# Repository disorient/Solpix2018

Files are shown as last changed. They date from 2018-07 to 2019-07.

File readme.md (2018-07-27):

# SolPix solar light flasher

This is a small mod board for converting a normal, non flashing [solar light](http://pdf.lowes.com/installationguides/840623104422_install.pdf)

## Installation Steps
briefly:

1. disassemble top of case, removing clear plastic top, 4 screws, black plastic lid, rubber gasket.
2. cut D2 diode leaving as much of the wire on it's leads attached to the board.
3. solder in the mod board along its long edge, with components facing up.
4. solder a wire from the remaining pad on the mod board to a gnd connection on the original board.
5. turn on to test.
6. reassemble top of case.

## Building the firmware
The flasher uses a [WCH CH554 microcontroller](www.wch.cn/products/CH554.html) and is programmed using the [CH554 SDCC](https://github.com/Blinkinlabs/ch554_sdcc) toolchain. It should work under macOS, Linux, and Windows (but was developed under a Windows environment). Once the toolchain is set up, the firmware can be built by running 'make' in the firware directory. Pre-compiled firmware releases are also available in the releases/ directory.

A nice feature of the WCH parts is that they have a hardware USB peripheral with a built-in bootloader, so they can be programmed without needing an extra tool. Pads for the USB connections are available on one edge of the PCB.

## PCB design
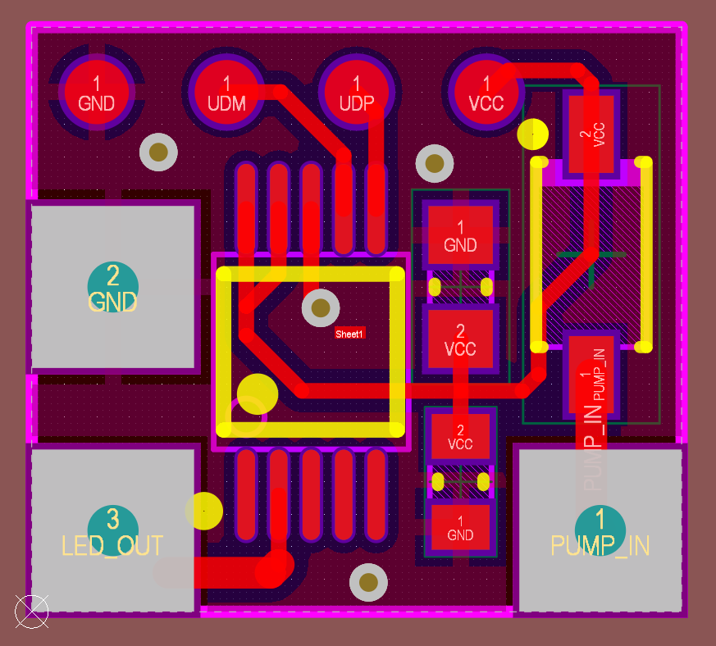
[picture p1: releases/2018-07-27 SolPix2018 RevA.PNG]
PCB image


The PCB was designed in Altium. The schematics and gerber for the release are available in the releases/ subdirectoy.

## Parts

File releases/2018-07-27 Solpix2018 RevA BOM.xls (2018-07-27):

PartType | Designator | Comment | Description | ComponentLink2URL | Pins | LibRef | Manufacturer | Quantity | Model:Footprint
CAP 2.2uF 6.3V 0603(1608) | C1 | CAP 2.2uF 6.3V 0603(1608) | CAP 2.2uF 6.3V ±10% 0603 (1608 Metric) Thickness 1mm SMD |  | 2.0 | CMP-1035-02754-1 |  | 1.0 | Chip Capacitor, Body 1.6x0.8mm, Height 1.0mm, IPC High Density
1N5819HW-7-F | D1 | 1N5819HW-7-F | 1.0 A Surface Mount Schottky Barrier Rectifier, 40 V, -65 to 125 degC, 2-Pin SOD-123 Package, RoHS, Tape and Reel | http://www.diodes.com/datasheets/ds30217.pdf | 2.0 | CMP-0303-00003-1 | Diodes Inc | 1.0 | SOD-123, 2-Leads, Body 2.85x1.7mm (max), Pitch 3.7mm
10K 5% 0603(1608) | R1 | 10K 5% 0603(1608) | 10K 0.1W 5% 0603 (1608 Metric) SMD |  | 2.0 | CMP-1012-00098-1 |  | 1.0 | Chip Resistor, Body 1.6x0.8mm, IPC Medium Density
CH554E | U1 | CH554E | 8-bit enhanced USB microcontroller |  | 10.0 | CH554E | WCH | 1.0 | Footprint from SZLCSC example

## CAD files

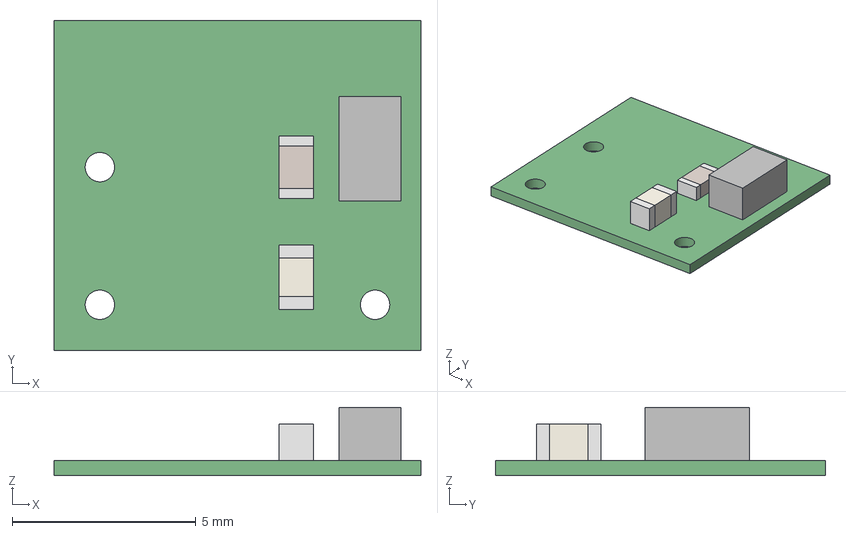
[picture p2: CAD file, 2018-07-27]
releases/2018-07-27 Solpix2018 RevA.step
10.0 x 9.00 x 1.86 mm
Board
Extruded x 7

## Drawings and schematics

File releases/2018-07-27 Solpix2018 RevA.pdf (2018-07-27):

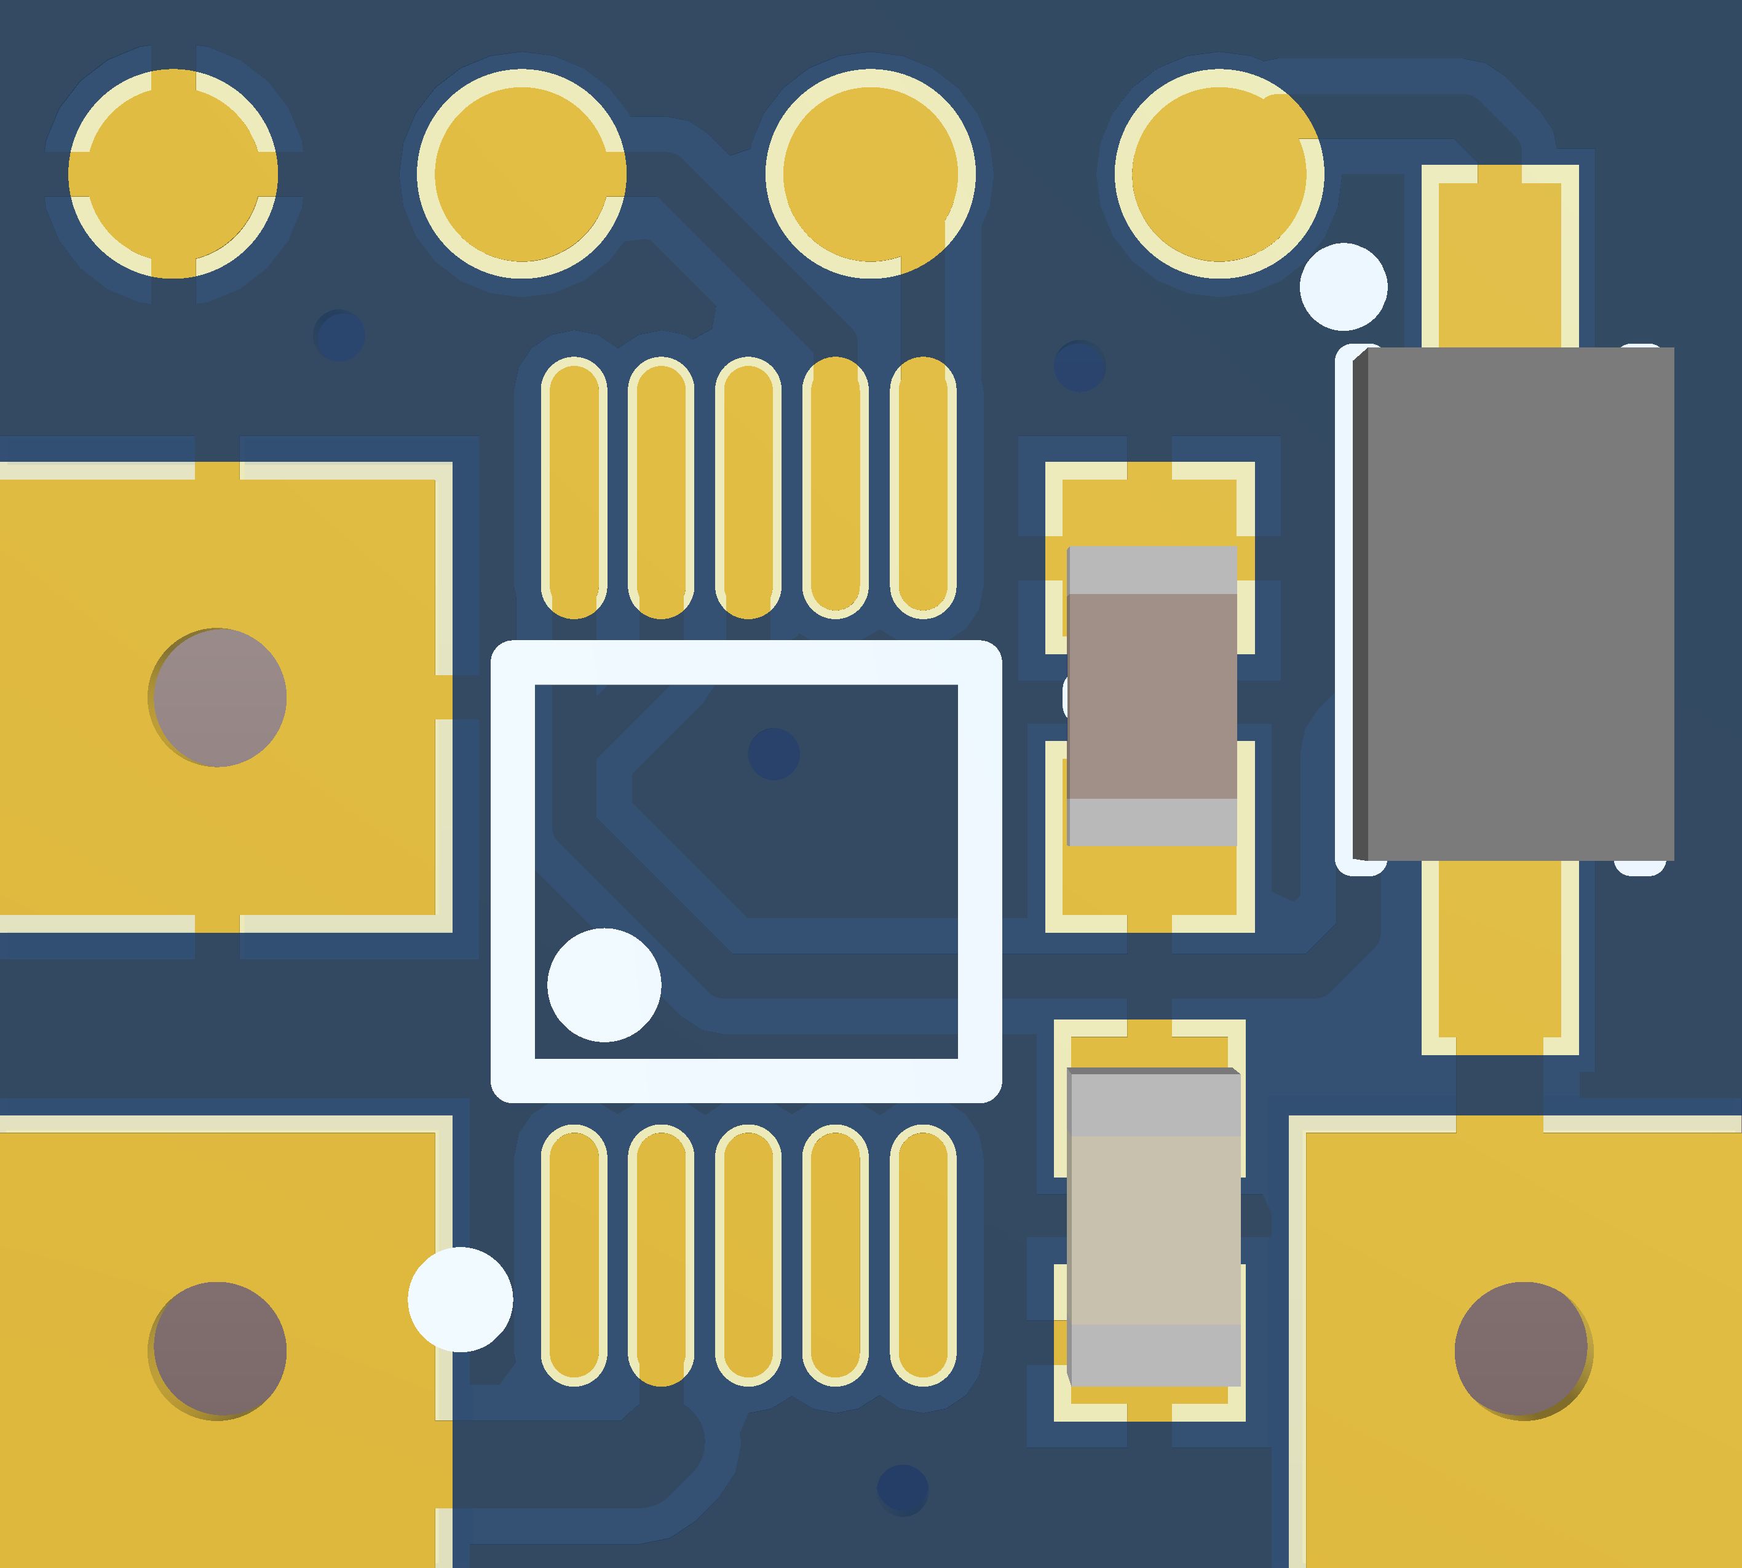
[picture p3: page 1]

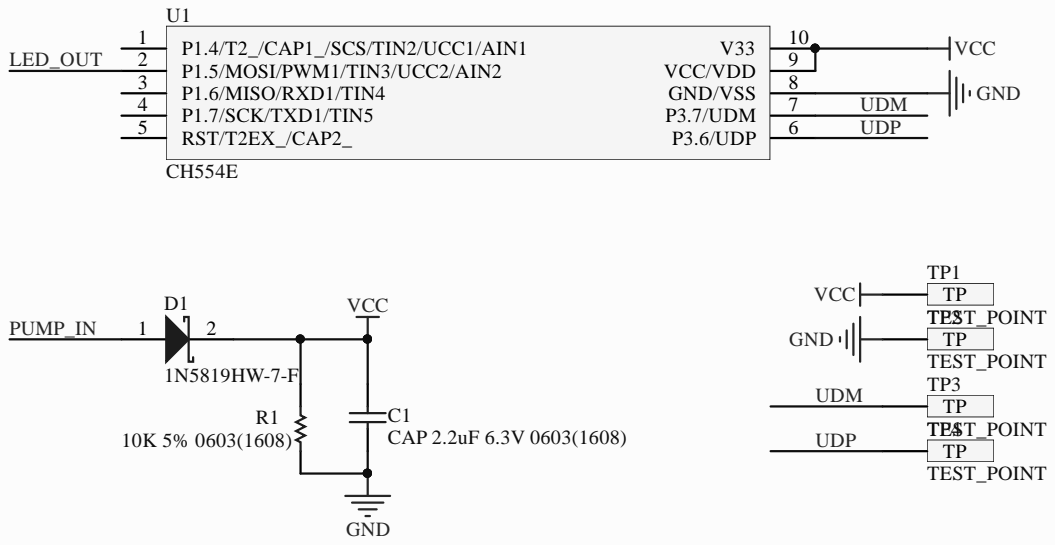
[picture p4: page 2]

* Title:

Project: PCB_Project1.PrjPCB | Revision: *

Date: 7/27/2018 Time: 5:05:16 PM | Sheet * of *

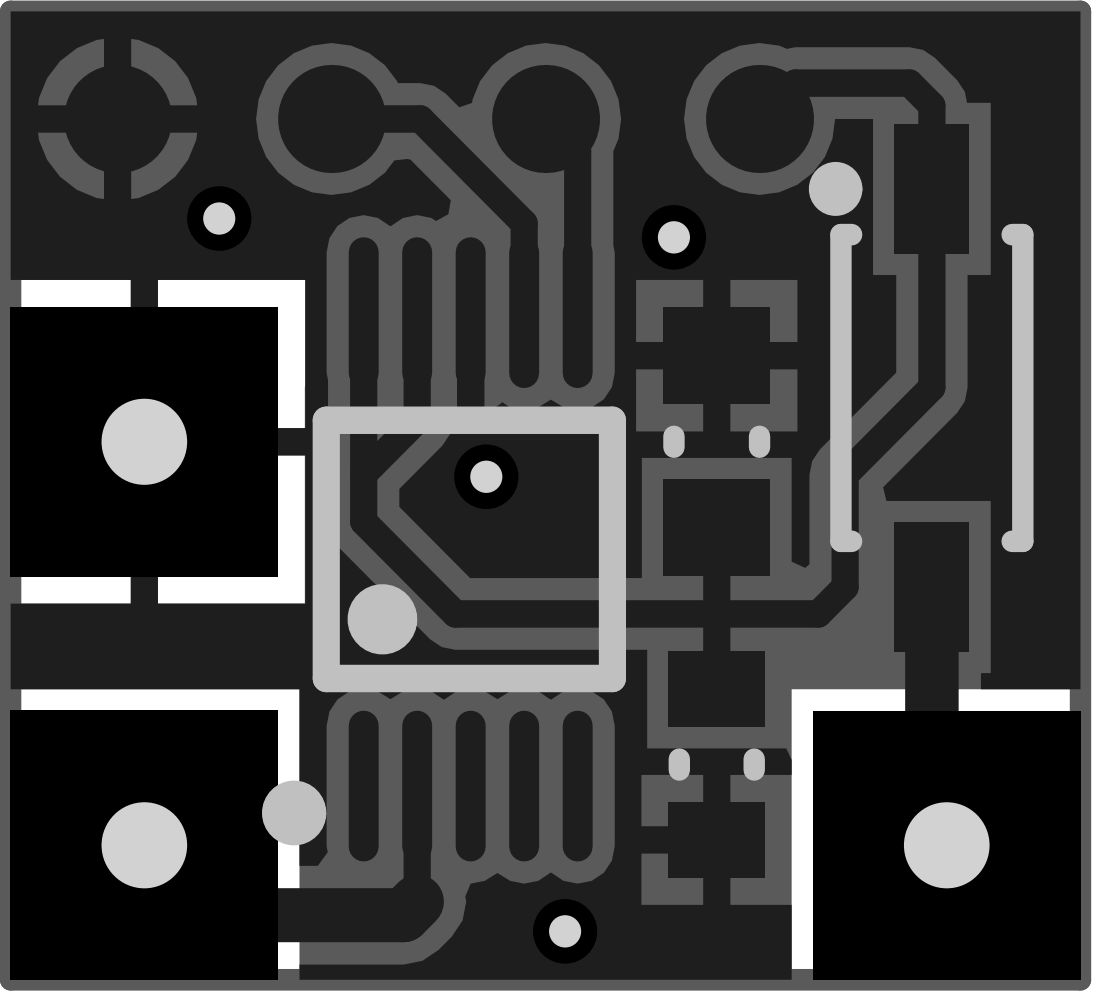
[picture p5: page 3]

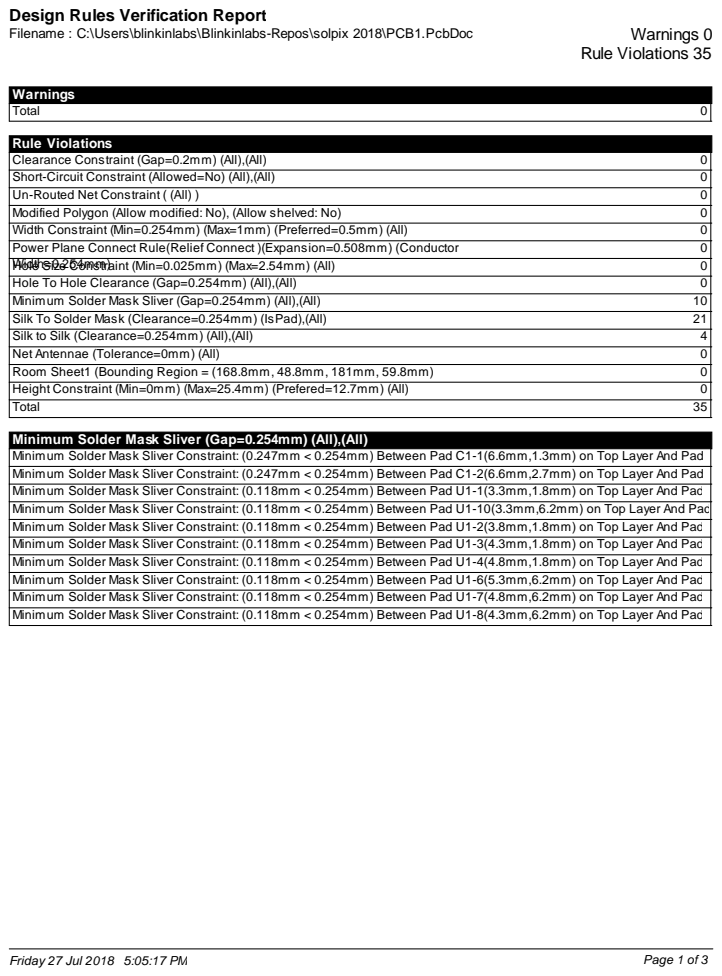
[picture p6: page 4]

Design Rules Verification Report

Rule Violations
Power Plane Connect Rule(Relief Connect )(Expansion=0.508mm) (Conductor
Width=0.254mm)

Minimum Solder Mask Sliver (Gap=0.254mm) (All),(All)
Minimum Solder Mask Sliver Constraint: (0.247mm < 0.254mm) Between Pad C1-1(6.6mm,1.3mm) on Top Layer And Pad
Minimum Solder Mask Sliver Constraint: (0.247mm < 0.254mm) Between Pad C1-2(6.6mm,2.7mm) on Top Layer And Pad
Minimum Solder Mask Sliver Constraint: (0.118mm < 0.254mm) Between Pad U1-1(3.3mm,1.8mm) on Top Layer And Pad
Minimum Solder Mask Sliver Constraint: (0.118mm < 0.254mm) Between Pad U1-10(3.3mm,6.2mm) on Top Layer And Pad
Minimum Solder Mask Sliver Constraint: (0.118mm < 0.254mm) Between Pad U1-2(3.8mm,1.8mm) on Top Layer And Pad
Minimum Solder Mask Sliver Constraint: (0.118mm < 0.254mm) Between Pad U1-3(4.3mm,1.8mm) on Top Layer And Pad
Minimum Solder Mask Sliver Constraint: (0.118mm < 0.254mm) Between Pad U1-4(4.8mm,1.8mm) on Top Layer And Pad
Minimum Solder Mask Sliver Constraint: (0.118mm < 0.254mm) Between Pad U1-6(5.3mm,6.2mm) on Top Layer And Pad
Minimum Solder Mask Sliver Constraint: (0.118mm < 0.254mm) Between Pad U1-7(4.8mm,6.2mm) on Top Layer And Pad
Minimum Solder Mask Sliver Constraint: (0.118mm < 0.254mm) Between Pad U1-8(4.3mm,6.2mm) on Top Layer And Pad

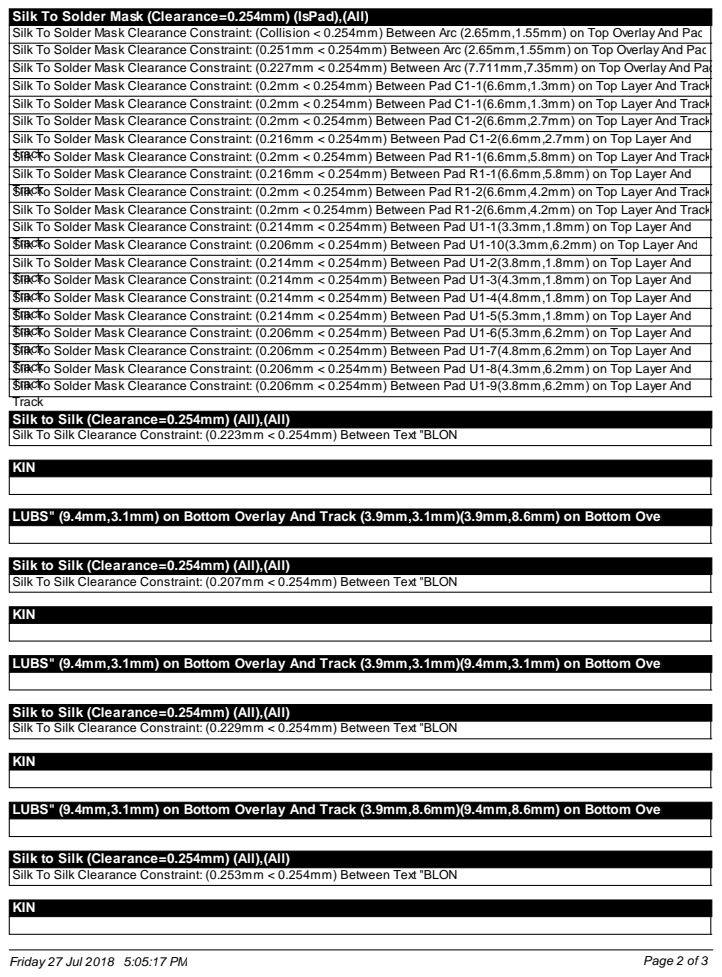
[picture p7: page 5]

Silk To Solder Mask (Clearance=0.254mm) (IsPad),(All)
Silk To Solder Mask Clearance Constraint: (Collision < 0.254mm) Between Arc (2.65mm,1.55mm) on Top OverlayAnd Pad
Silk To Solder Mask Clearance Constraint: (0.251mm < 0.254mm) Between Arc (2.65mm,1.55mm) on Top OverlayAnd Pad
Silk To Solder Mask Clearance Constraint: (0.227mm < 0.254mm) Between Arc (7.711mm,7.35mm) on Top OverlayAnd Pad
Silk To Solder Mask Clearance Constraint: (0.2mm < 0.254mm) Between Pad C1-1(6.6mm,1.3mm) on Top Layer And Track
Silk To Solder Mask Clearance Constraint: (0.2mm < 0.254mm) Between Pad C1-2(6.6mm,2.7mm) on Top Layer And Track
Silk To Solder Mask Clearance Constraint: (0.216mm < 0.254mm) Between Pad C1-2(6.6mm,2.7mm) on Top Layer And
Silk To Solder Mask Clearance Constraint: (0.216mm < 0.254mm) Between Pad R1-1(6.6mm,5.8mm) on Top Layer And
Silk To Solder Mask Clearance Constraint: (0.2mm < 0.254mm) Between Pad R1-2(6.6mm,4.2mm) on Top Layer And Track
Silk To Solder Mask Clearance Constraint: (0.214mm < 0.254mm) Between Pad U1-1(3.3mm,1.8mm) on Top Layer And
Silk To Solder Mask Clearance Constraint: (0.214mm < 0.254mm) Between Pad U1-2(3.8mm,1.8mm) on Top Layer And
Track
Silk to Silk (Clearance=0.254mm) (All),(All)
Silk To Silk Clearance Constraint: (0.223mm < 0.254mm) Between Text "BLON

Siralk ckTo Solder Mask Clearance Constraint: (0.2mm < 0.254mm) Between Pad R1-1(6.6mm,5.8mm) on Top Layer And Track

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

Siralk ckTo Solder Mask Clearance Constraint: (0.206mm < 0.254mm) Between Pad U1-10(3.3mm,6.2mm) on Top Layer And

Siralk ckTo Solder Mask Clearance Constraint: (0.214mm < 0.254mm) Between Pad U1-3(4.3mm,1.8mm) on Top Layer And
Siralk ckTo Solder Mask Clearance Constraint: (0.214mm < 0.254mm) Between Pad U1-4(4.8mm,1.8mm) on Top Layer And
Siralk ckTo Solder Mask Clearance Constraint: (0.214mm < 0.254mm) Between Pad U1-5(5.3mm,1.8mm) on Top Layer And
Siralk ckTo Solder Mask Clearance Constraint: (0.206mm < 0.254mm) Between Pad U1-6(5.3mm,6.2mm) on Top Layer And
Siralk ckTo Solder Mask Clearance Constraint: (0.206mm < 0.254mm) Between Pad U1-7(4.8mm,6.2mm) on Top Layer And
Siralk ckTo Solder Mask Clearance Constraint: (0.206mm < 0.254mm) Between Pad U1-8(4.3mm,6.2mm) on Top Layer And
Siralk ckTo Solder Mask Clearance Constraint: (0.206mm < 0.254mm) Between Pad U1-9(3.8mm,6.2mm) on Top Layer And

LUBS" (9.4mm,3.1mm) on Bottom Overlay And Track (3.9mm,3.1mm)(3.9mm,8.6mm) on Bottom Overl

Silk To Silk Clearance Constraint: (0.207mm < 0.254mm) Between Text "BLON

LUBS" (9.4mm,3.1mm) on Bottom Overlay And Track (3.9mm,3.1mm)(9.4mm,3.1mm) on Bottom Overl

Silk To Silk Clearance Constraint: (0.229mm < 0.254mm) Between Text "BLON

LUBS" (9.4mm,3.1mm) on Bottom Overlay And Track (3.9mm,8.6mm)(9.4mm,8.6mm) on Bottom Overl

Silk To Silk Clearance Constraint: (0.253mm < 0.254mm) Between Text "BLON
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

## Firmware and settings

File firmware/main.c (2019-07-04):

// Flash an LED slowly, while in low power mode

#include <ch554.h>
#include <debug.h>

#define OFFBOARD_LED_PIN 5

SBIT(OFFBOARD_LED, 0x90, OFFBOARD_LED_PIN);

void main() {
    CfgFsys();
    mDelaymS(5);

    P1_MOD_OC = P1_MOD_OC & ~(1<<OFFBOARD_LED_PIN);
    P1_DIR_PU = P1_DIR_PU | ~(1<<OFFBOARD_LED_PIN);

    while (1) {
        OFFBOARD_LED = 1;

    	mDelaymS(200);
    	mDelaymS(200);
    	mDelaymS(200);
    	mDelaymS(200);
    	mDelaymS(200);
    	mDelaymS(200);
    	mDelaymS(200);

    	mDelaymS(200);
    	mDelaymS(200);
    	mDelaymS(200);
    	mDelaymS(200);
    	mDelaymS(200);
    	mDelaymS(200);
    	mDelaymS(200);

    	mDelaymS(200);
    	mDelaymS(200);
    	mDelaymS(200);
    	mDelaymS(200);
    	mDelaymS(200);
    	mDelaymS(200);
    	mDelaymS(200);

        OFFBOARD_LED = 0;

    	mDelaymS(200);
    	mDelaymS(200);
    	mDelaymS(200);
    	mDelaymS(200);
    	mDelaymS(200);
    	mDelaymS(200);
    	mDelaymS(200);
    }
}

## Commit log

2018-07-27 Add RevA PCB
    [2018-07-27 Solpix2018 RevA BOM.xls, 2018-07-27 Solpix2018 RevA.step]
2018-07-27 Fix gerber release (was missing drill layer)
